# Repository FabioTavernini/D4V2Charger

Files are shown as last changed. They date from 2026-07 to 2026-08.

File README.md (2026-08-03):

# D4v2Charger

A work-in-progress proof of concept for adding built-in USB-C charging to the
[Emisar D4v2](https://intl-outdoor.com/emisar-d4v2-high-power-led-flashlight.html) flashlight, using a
pogo-pin connector in place of removing the cell to charge it externally.

The charger PCB is a disc that sits sandwiched between the flashlight body
tube and the head, in the same joint where they normally screw together. A
spring contact on the board presses against the cell's positive terminal,
while the pogo-pin connector protrudes to the side to bring in USB-C power
through the body wall.

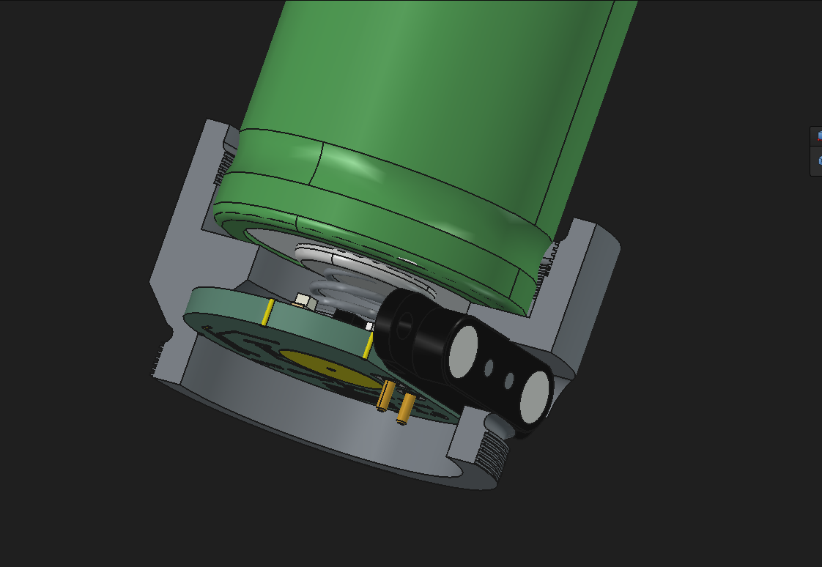
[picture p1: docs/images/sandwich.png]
SandwichBoard


*Cutaway render: cell (green) above, charger PCB sandwiched at the
body/head joint below, with the spring contact touching the cell's positive
terminal and the pogo-pin connector (black) sticking out to the side.*

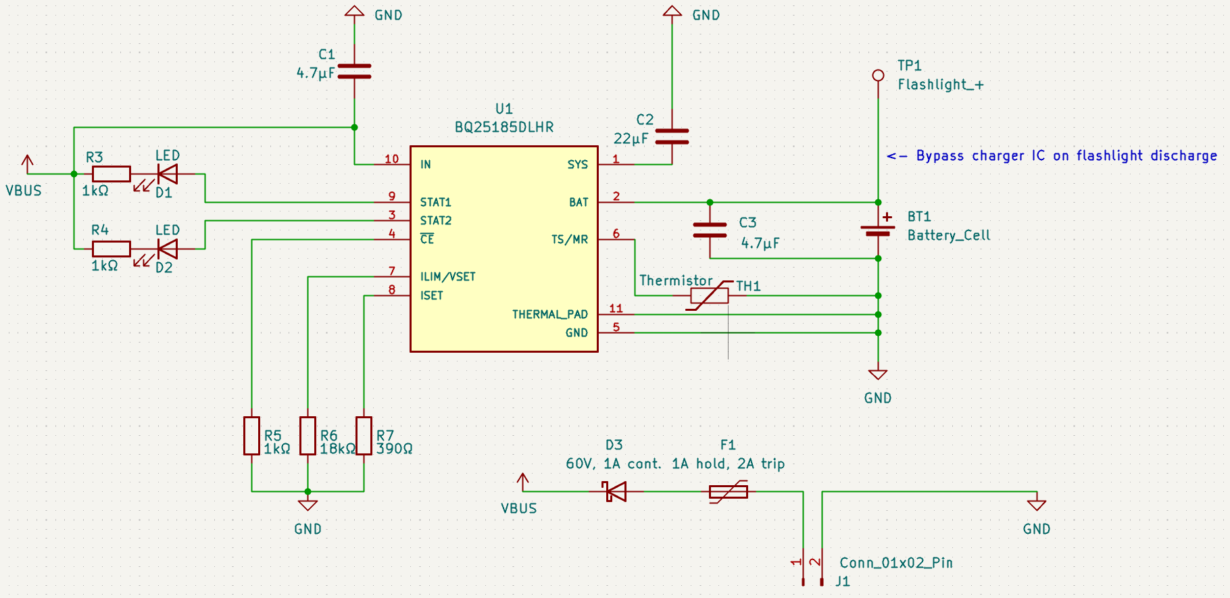
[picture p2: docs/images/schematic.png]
Schematics


*Screenshot of Schematic (May be out of date lol)*

## Status

Early prototype / proof of concept. Nothing here has been validated in a
final build yet — expect rough edges, and treat all files as subject to
change.

## How it works

- A small ring-shaped PCB is sandwiched between the flashlight body and
  head, and charges the cell via a
  [TI BQ25185](https://www.ti.com/product/BQ25185) single-cell Li-ion linear
  charger (with integrated power path).
- A spring contact on the board makes the positive connection to the cell,
  so no wiring or modification of the cell itself is needed.
- Power comes in through a pair of spring-loaded pogo pins rather than a
  connector mounted directly on the PCB, so no permanent cutout is needed
  for a USB-C receptacle on the board itself.
- A custom pogo-pin connector part and a modified flashlight body/case were
  designed to accommodate the charging contacts and let the PCB sandwich
  fit at the body/head joint.

## Repo contents

- `pcb/` — KiCad project for the charger board
  - `D4v2Charger.kicad_pro` / `.kicad_sch` / `.kicad_pcb` — schematic and PCB layout
  - `D4v2Charger.step` — 3D export of the finished board
  - `PogoPinConnector/` — FreeCAD model and STEP export of the pogo-pin connector
  - `D4v2Charger-backups/` — automatic KiCad backups (safe to ignore)
- `case/` — FreeCAD model of the modified flashlight body/case to fit the
  charging hardware

## Tools used

- [KiCad](https://www.kicad.org/) for schematic capture and PCB layout
- [FreeCAD](https://www.freecad.org/) for mechanical/case design

## Disclaimer

This is a hobbyist mod to a battery-powered lighting device. Modifying
charging circuitry and battery contacts carries fire/safety risk if done
incorrectly. Use at your own risk.

## License

Licensed under the [CERN Open Hardware Licence Version 2 - Strongly
Reciprocal](LICENSE) (CERN-OHL-S-2.0).

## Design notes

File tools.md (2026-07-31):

# Tools

Equipment needed to actually build and fit this board, beyond the parts in
[`BOM.csv`](./BOM.csv) and the design files in [`pcb/`](./pcb) and
[`case/`](./case). Software used to design the project (KiCad, FreeCAD) is
listed in the main [README](./README.md#tools-used).

## PCB assembly

The board is a 1.6mm, 2-layer design with parts on both sides, and the
smallest packages are the 0402 caps/resistors — hand-placing those without
a stencil is the fiddly part. Planned process: manual paste dotting +
hot plate reflow (no stencil ordered, board too small to justify it).

- Hot plate (cheap AliExpress hot plate + controller kit) as the reflow
  source. Heat conducts up through the board copper, so it also reflows
  the BQ25185's exposed thermal pad fine without needing hot air.
- Solder paste in a syringe with a fine (~22-25ga) blunt needle tip, for
  dotting paste onto pads by hand since there's no stencil — this is the
  part that needs the most care at 0402 size
- Fine-tip soldering iron for touch-up/rework and for the through-hole
  pogo-pin/spring contact if it isn't reflowed
- Kapton tape or similar heat-safe tape to hold the board flat/in place
  on the hot plate
- Flux pen + isopropyl alcohol for cleanup after soldering
- Fine ESD tweezers and a magnifier/loupe or microscope — needed for
  placing 0402 passives and 0603 LEDs, and for nudging the BQ25185 into
  place on its 0.4mm-pitch pads
- Multimeter, for continuity/short checks before power-up, especially
  since the board edge is copper-plated and acts as the ground/negative
  contact against the flashlight case — an accidental bridge here is a
  direct short across the cell
- USB-C power source (a basic 5V source is enough, no PD negotiation
  needed) to test charging once assembled
- Bench power supply / current-limited source recommended for first
  power-up, to catch a bad solder joint before it takes the cell with it

## Case & mechanical fit

The case mod and pogo-pin connector are custom FreeCAD parts
(`case/Case.FCStd`, `pcb/PogoPinConnector/`), fitted into the D4v2's
body/head threaded joint (`case/Thread_tests/ThreadTester.FCStd`):

- Means to cut/print the modified body threads to match the D4v2's
  joint — a tap matching the body's thread pitch if machining an
  existing aluminum body, or a 3D printer/CNC if producing a test or
  replacement part. Print/machine and check fit with the thread tester
  model before committing to the real body.
- Calipers, to confirm the sandwiched board's thickness and the pogo-pin
  standoff height fit the joint gap before final assembly
- Small pin press or arbor press, for seating the pogo pins into the
  connector housing without bending them
- Drill/reamer sized to the pogo-pin housing bore, if machining the body
  directly rather than printing a new part

## Final assembly

- No tools needed to reassemble the body/head — it's a hand-tightened
  threaded joint
- Isopropyl alcohol and lint-free wipes for a final clean before closing
  everything up (flux residue near the cell contact is worth avoiding)

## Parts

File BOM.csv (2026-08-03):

Id | Designator | Footprint | Quantity | Designation | Supplier and ref | comment | Link | price
1 | TP1 | TestPoint_Pad_D6.0mm_spring | 1 | Flashlight_+ |  | Spring, 6mm diameter 25° banking if available, for + terminal | https://de.aliexpress.com/item/1005005667884016.html
2 | U1 | Texas_DLH0010A_WSON-10-1EP_2.2x2mm_P0.4mm_EP0.9x1.5mm | 1 | BQ25185DLHR |  | digikey, pretty expensive | https://www.digikey.com/en/products/detail/texas-instruments/BQ25185DLHR/21769368 | 2.28
3 | D3 | DIO_PMEG6010CEJF | 1 | 60V, 1A cont. |  | not available, see alternatives | https://de.aliexpress.com/item/1005012406460192.html
4 | D1,D2 | LED_0603_1608Metric | 2 | LED |  | 1000pcs reel | https://de.aliexpress.com/item/1005009084941790.html | 4.25
5 | C2 | C_0402_1005Metric | 1 | 22µF |  | 50pcs | https://de.aliexpress.com/item/1005005108653334.html | 3.47
6 | C1,C3 | C_0402_1005Metric | 2 | 4.7µF |  | 6.3v 50pcs | https://de.aliexpress.com/item/1005012364450156.html | 1.31
7 | R4,R5,R3 | R_0402_1005Metric | 3 | 1kΩ |  | 100pcs | https://de.aliexpress.com/item/1005008851185252.html | 0.21
8 | R6 | R_0402_1005Metric | 1 | 18kΩ |  |  | https://de.aliexpress.com/item/1005008851185252.html | 0.21
9 | R7 | R_0402_1005Metric | 1 | 390Ω |  |  | https://de.aliexpress.com/item/1005008851185252.html | 0.21
10 | F1 | 0402L100SLKR | 1 | 1A hold, 2A trip |  | digikey, pretty expensive | https://www.digikey.com/en/products/detail/littelfuse-inc/0402L100SLKR/12807017 | 3.28
11 | J1 | PinHeader_1x02_P2.54mm_Vertical | 1 | Conn_01x02_Pin |  | 5pcs | https://de.aliexpress.com/item/1005006531774076.html | 10.39
12 | TH1 | THERM_NTCG103JF103FT1 | 1 | Thermistor |  | TDK NTCG103JF103FT1, 10kΩ NTC 0402

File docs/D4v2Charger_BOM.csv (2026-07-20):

Id | Designator | Footprint | Quantity | Designation | Supplier and ref
1 | TP1 | TestPoint_Pad_D6.0mm_spring | 1 | Flashlight_+
2 | U1 | Texas_DLH0010A_WSON-10-1EP_2.2x2mm_P0.4mm_EP0.9x1.5mm | 1 | BQ25185DLHR
3 | D3 | DIO_PMEG6010CEJF | 1 | 60V, 1A cont.
4 | D1,D2 | LED_0603_1608Metric | 2 | LED
5 | C2 | C_0402_1005Metric | 1 | 22µF
6 | C1,C3 | C_0402_1005Metric | 2 | 4.7µF
7 | R4,R5,R3 | R_0402_1005Metric | 3 | 1kΩ
8 | R6 | R_0402_1005Metric | 1 | 18kΩ
9 | R7 | R_0402_1005Metric | 1 | 390Ω
10 | F1 | 0402L100SLKR | 1 | 1A hold, 2A trip
11 | J1 | PinHeader_1x02_P2.54mm_Vertical | 1 | Conn_01x02_Pin
12 | R8 | R_0402_1005Metric | 1 | 10kΩ

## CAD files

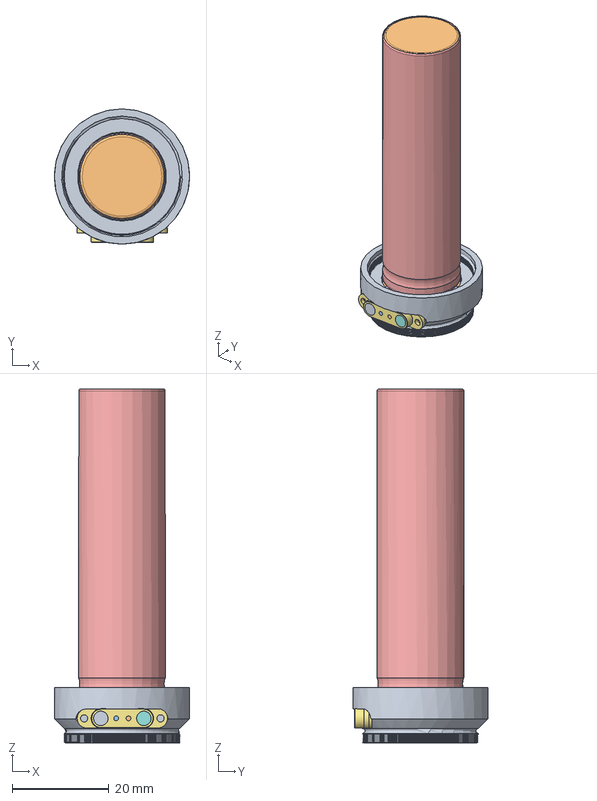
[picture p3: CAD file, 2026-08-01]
case/Case.FCStd
28.0 x 28.0 x 73.3 mm
18650 Battery
18650 Battery001
18650 Battery002
18650 Battery003
Spring_6mm-Body
Texas_DLH0010A_WSON-10-1EP_2.2x2mm_P0.4mm_EP0.9x1.5mm
Pads
Pads001
LED_0603_1608Metric
C_0402_1005Metric
C_0402_1005Metric001
LED_0603_1608Metric001
R_0402_1005Metric
R_0402_1005Metric001
R_0402_1005Metric002
R_0402_1005Metric003
Pads003
Pads004
DiodeBody
R_0402_1005Metric004
Magnets
Magnets001
Pads006
Pads007
Pins
Pins001
C_0402_1005Metric002
NTCG103JF103FT1
NTCG103JF103FT001
NTCG103JF103FT002
D4v2Charger_copper
D4v2Charger_copper001
D4v2Charger_copper002
D4v2Charger_copper003
D4v2Charger_copper004
D4v2Charger_copper005
D4v2Charger_copper006
D4v2Charger_copper007
D4v2Charger_copper008
D4v2Charger_copper009
D4v2Charger_copper010
D4v2Charger_copper011
D4v2Charger_copper012
D4v2Charger_copper013
D4v2Charger_copper014
D4v2Charger_copper015
D4v2Charger_copper016
D4v2Charger_copper017
D4v2Charger_copper018
D4v2Charger_copper019
D4v2Charger_copper020
D4v2Charger_copper021
D4v2Charger_copper022
D4v2Charger_copper023
D4v2Charger_pad
D4v2Charger_pad001
D4v2Charger_pad002
D4v2Charger_pad003
D4v2Charger_pad004
D4v2Charger_pad005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

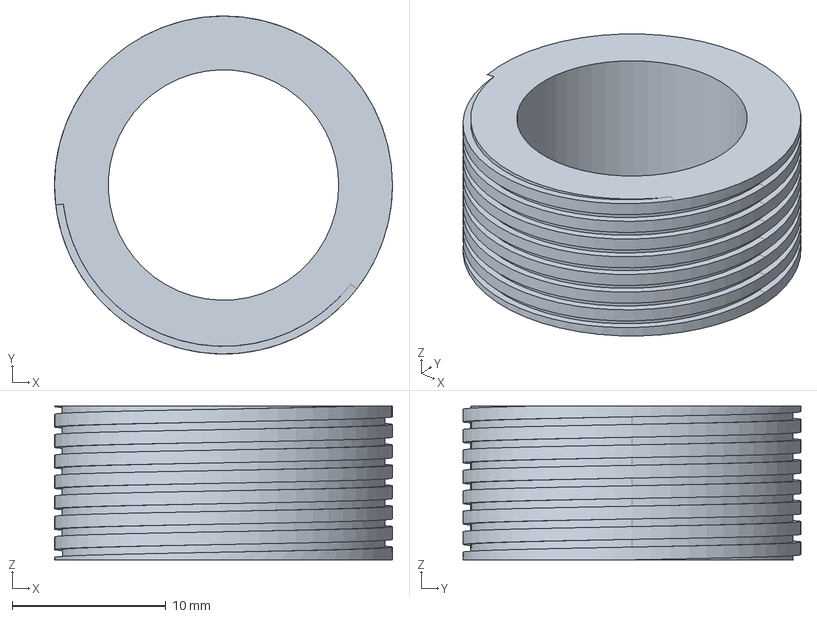
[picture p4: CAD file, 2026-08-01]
case/Thread_tests/ThreadTester.FCStd
22.0 x 22.0 x 10.0 mm

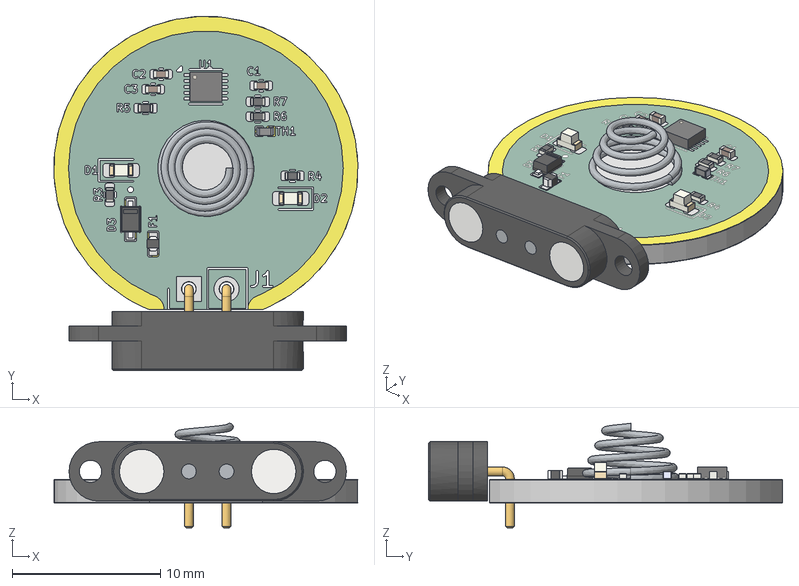
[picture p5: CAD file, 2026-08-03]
pcb/D4v2Charger.step
20.5 x 23.9 x 7.05 mm
Spring_6mm-Body
Texas_DLH0010A_WSON-10-1EP_2.2x2mm_P0.4mm_EP0.9x1.5mm
Pads x 3
LED_0603_1608Metric x 2
C_0402_1005Metric x 3
R_0402_1005Metric x 5
DiodeBody
Magnets
Pins
NTCG103JF103FT1
D4v2Charger_copper
D4v2Charger_pad
D4v2Charger_via
D4v2Charger_silkscreen
D4v2Charger_soldermask
D4v2Charger_PCB

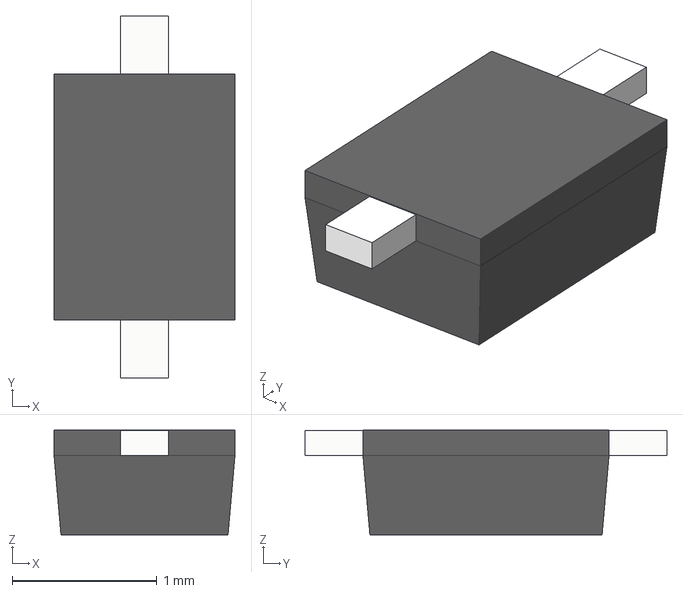
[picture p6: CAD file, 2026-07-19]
pcb/DIO_PMEG6010CEJF/DIO_PMEG6010CEJF.step
1.25 x 2.50 x 0.725 mm
Pads

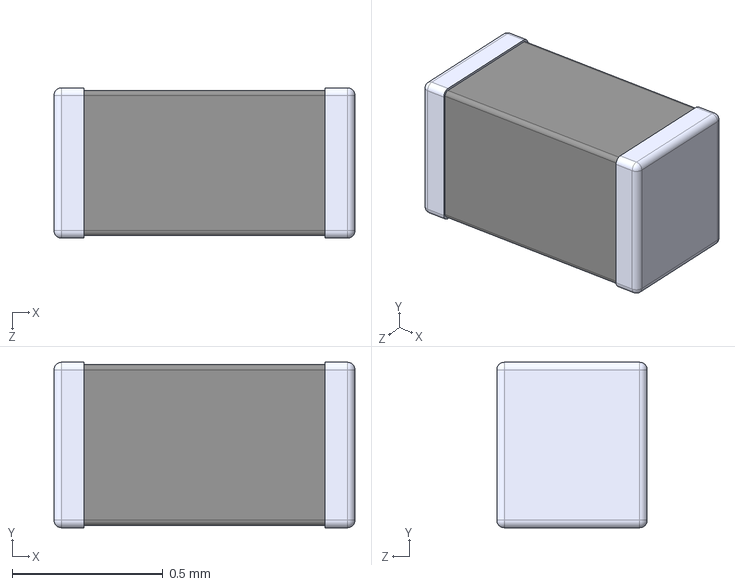
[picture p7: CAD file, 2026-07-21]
pcb/NTCG103JF103FT1/NTCG103JF103FT1.step
1.00 x 0.55 x 0.5 mm

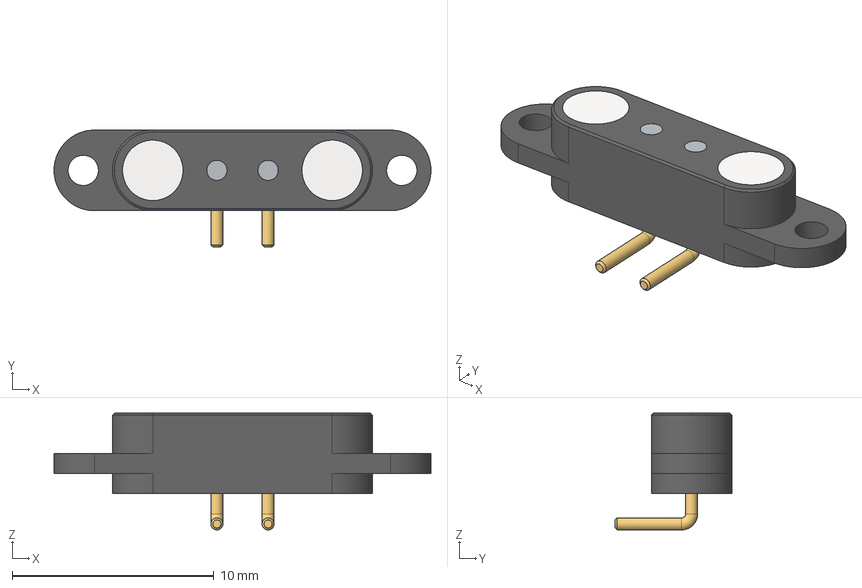
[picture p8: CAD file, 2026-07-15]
pcb/PogoPinConnector/PogoPinConnector.step
18.7 x 5.80 x 5.80 mm
Magnets
Pads
Pins

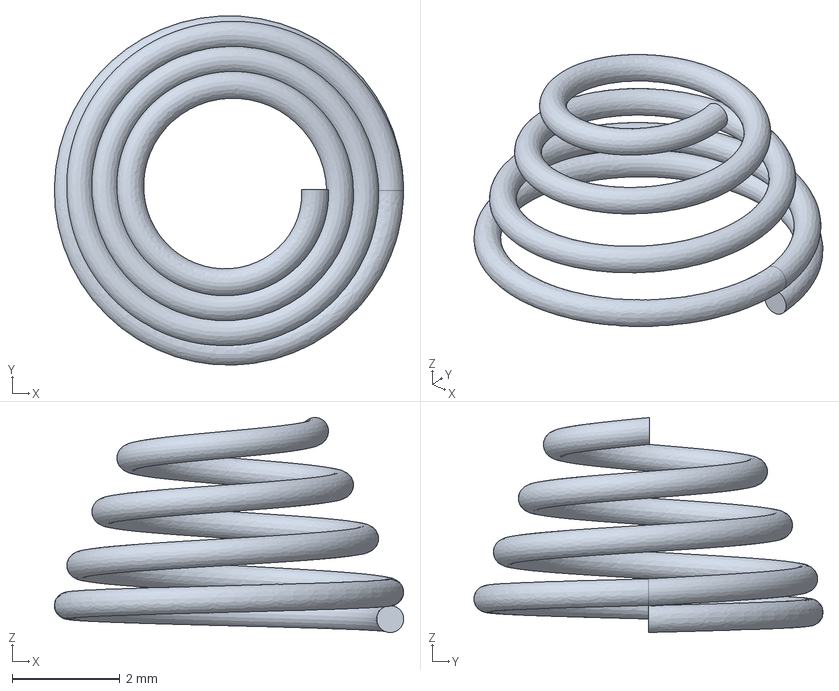
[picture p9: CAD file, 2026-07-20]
pcb/TestPad_SpringModel/Spring_6mm.FCStd
6.50 x 6.49 x 4.00 mm

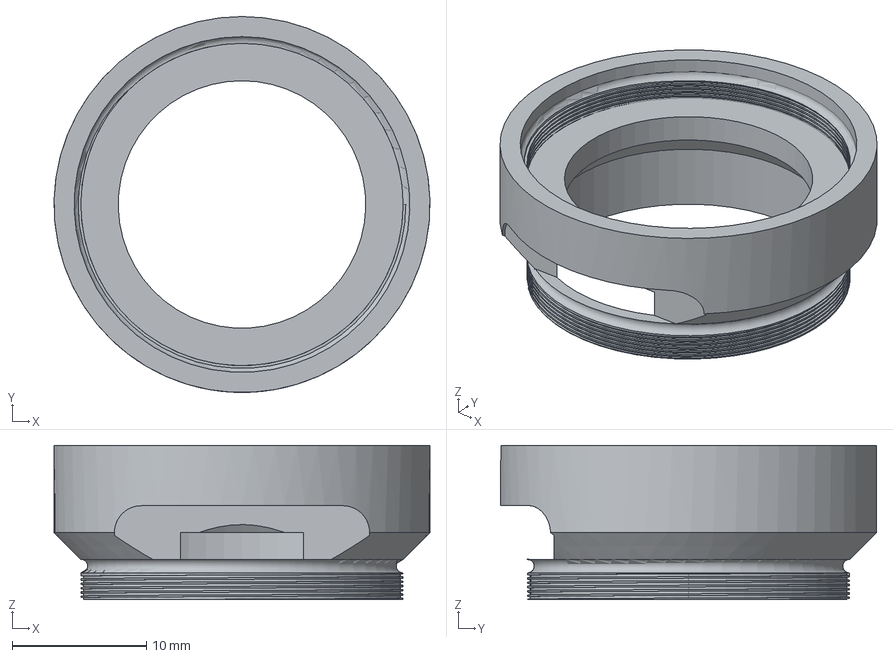
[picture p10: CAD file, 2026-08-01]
case/Case-Body.step
28.0 x 28.0 x 11.5 mm

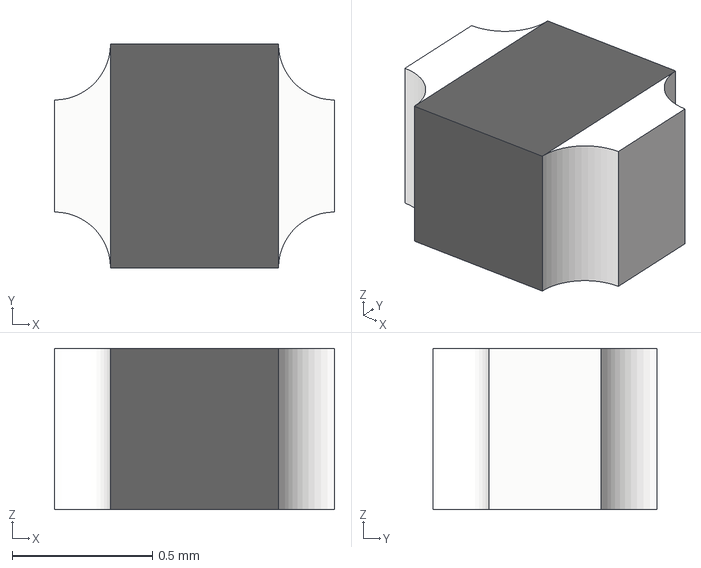
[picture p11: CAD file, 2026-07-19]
pcb/Littlefuse_0406L_0402L100SLKR_0402L100SL/0402L100SL.step
1.00 x 0.8 x 0.575 mm
Pads
DiodeBody

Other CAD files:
case/Thread_tests/ThreadTester-Male.step
pcb/TestPad_SpringModel/Spring_6mm-Body.step
pcb/DIO_PMEG6010CEJF/DIO_PMEG6010CEJF.FCStd
pcb/Littlefuse_0406L_0402L100SLKR_0402L100SL/0402L100SL.FCStd
pcb/PogoPinConnector/PogoPinConnector.FCStd

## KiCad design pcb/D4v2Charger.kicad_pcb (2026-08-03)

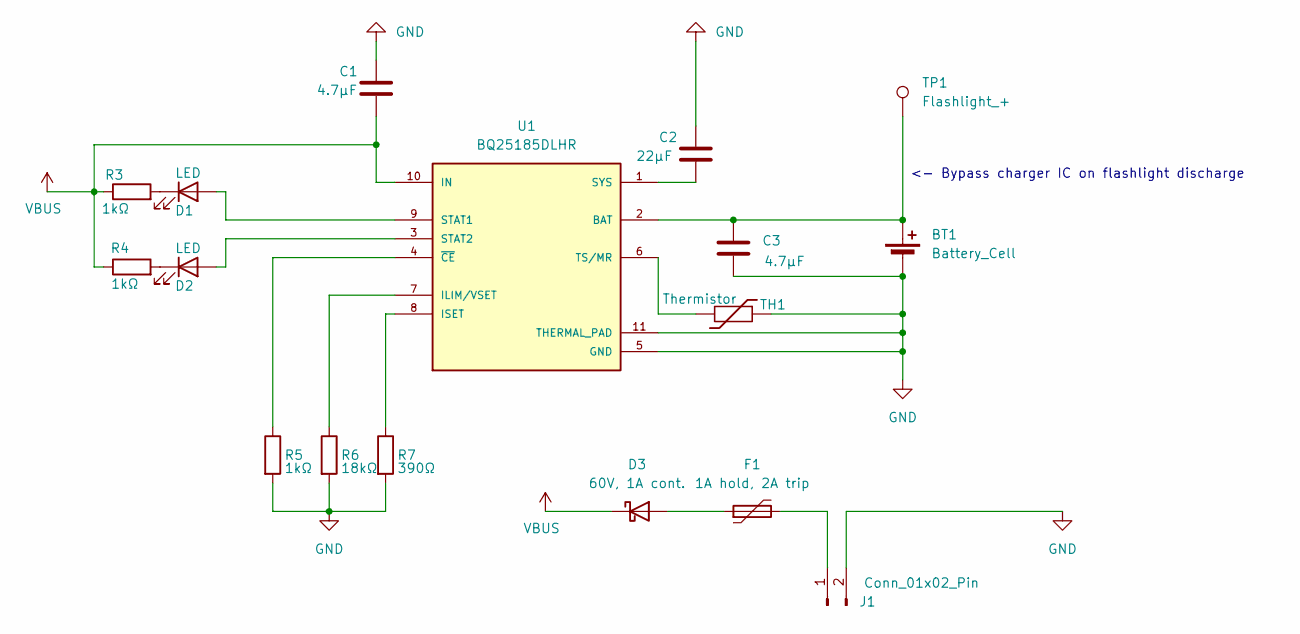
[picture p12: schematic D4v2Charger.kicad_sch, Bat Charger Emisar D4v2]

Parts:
BT1: Battery_Cell
C1, C3: 4.7µF; C_0402_1005Metric
C2: 22µF; C_0402_1005Metric
D1, D2: LED; LED_0603_1608Metric
D3: 60V, 1A cont.; DIO_PMEG6010CEJF
F1: 1A hold, 2A trip; 0402L100SLKR
J1: Conn_01x02_Pin; PinHeader_1x02_P2.54mm_Vertical
R3, R4, R5: 1kΩ; R_0402_1005Metric
R6: 18kΩ; R_0402_1005Metric
R7: 390Ω; R_0402_1005Metric
TH1: Thermistor; THERM_NTCG103JF103FT1
TP1: Flashlight_+; TestPoint_Pad_D6.0mm_spring
U1: BQ25185DLHR; Texas_DLH0010A_WSON-10-1EP_2.2x2mm_P0.4mm_EP0.9x1.5mm; PARTREV OCTOBER 2023

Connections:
GND: BT1.2 (-), C1.1, C2.1, C3.2, J1.2, R5.2, R6.2, R7.2, TH1.1, U1.5 (GND), U1.11 (THERMAL_PAD)
unnamed: BT1.1 (+), C3.1, TP1.1, U1.2 (BAT)
unnamed: D1.2 (A), U1.9 (STAT1)
unnamed: D1.1 (K), R3.2
unnamed: D2.2 (A), U1.3 (STAT2)
unnamed: D2.1 (K), R4.2
unnamed: D3.2 (A), F1.1
unnamed: F1.2, J1.1
unnamed: R6.1, U1.7 (ILIM/VSET)
unnamed: R7.1, U1.8 (ISET)
unnamed: C2.2, U1.1 (SYS)
unnamed: TH1.2, U1.6 (TS/MR)
unnamed: R5.1, U1.4 (~CE)
VBUS: C1.2, D3.1 (K), R3.1, R4.1, U1.10 (IN)

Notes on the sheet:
<- Bypass charger IC on flashlight discharge

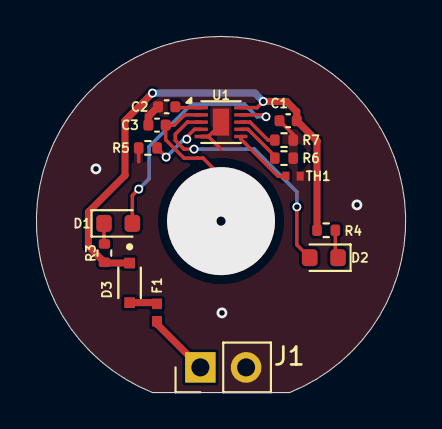
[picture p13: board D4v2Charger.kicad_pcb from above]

Board: 2 copper layers, 20.5 x 19.8 mm, 16 parts (0 on the bottom side), 14 nets.

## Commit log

2026-07-15 add rest of files
    [Case.FCStd, D4v2Charger.kicad_pcb, D4v2Charger.kicad_sch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]
2026-07-15 updates & license addition
    [Case.FCStd, D4v2Charger.kicad_pcb, D4v2Charger.kicad_sch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]
2026-07-15 updated pcb clearance for magnetic charger
    [D4v2Charger.kicad_pcb, D4v2Charger.kicad_sch]
2026-07-15 re-import pcb
    [Case.FCStd, D4v2Charger.step]
2026-07-15 import step case as linkgroup
    [Case.FCStd, D4v2Charger.kicad_pcb]
2026-07-16 SYS pin fix
2026-07-19 create diode 3dModel
    [D4v2Charger.kicad_pcb, D4v2Charger.kicad_sch, DIO_PMEG6010CEJF.FCStd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]
2026-07-19 create fuse 3dmodel
    [0402L100SL.FCStd, 0402L100SL.step, D4v2Charger.kicad_pcb]
2026-07-20 3dFootprint updates
    [Case.FCStd, D4v2Charger.kicad_pcb, D4v2Charger.kicad_sch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]
2026-07-20 updated step file & re-import
    [Case.FCStd, D4v2Charger.kicad_pcb, D4v2Charger.step]
2026-07-20 update pcb with spring contact for battery +
    [Case.FCStd, D4v2Charger.kicad_pcb, D4v2Charger.kicad_sch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]
2026-07-20 add screenshot and 18650 into model
    [Case.FCStd]
2026-07-20 add BOM
    [D4v2Charger_BOM.csv]
2026-07-20 update BOM
    [D4v2Charger.csv]
2026-07-21 add ntcg thremistor & drc resolve
    [D4v2Charger.kicad_pcb, D4v2Charger.kicad_sch, NTCG103JF103FT1.step]
2026-07-21 gerber export & clearance finalization
    [D4v2Charger-B_Cu.gbr, D4v2Charger-B_Mask.gbr, D4v2Charger-B_Paste.gbr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]
2026-07-21 re-import pad contact for 3dmodel
    [D4v2Charger.kicad_pcb]
2026-07-21 add thread testing 3dmodel
    [ThreadTester.FCStd]
2026-07-29 add board edge copper
    [D4v2Charger.kicad_pcb]
2026-07-31 add tools.md
    [BOM.csv]
2026-07-31 rename + mention pogo legs
2026-07-31 update gerber files
    [D4v2Charger-B_Cu.gbr, D4v2Charger-B_Mask.gbr, D4v2Charger-B_Paste.gbr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]
2026-07-31 pcb update (radius)
    [Case.FCStd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]
2026-07-31 re-export gerber files
    [D4v2Charger-B_Cu.gbr, D4v2Charger-B_Mask.gbr, D4v2Charger-B_Paste.gbr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]
2026-08-01 re-import pcb stepfile
    [Case.FCStd, D4v2Charger.kicad_pcb, D4v2Charger.step]
2026-08-01 thread tester
    [Case-Body.step, Case.FCStd, ThreadTester-Male.step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]
2026-08-01 add gnd stitch vias
    [D4v2Charger.kicad_pcb]
2026-08-03 update BOM and schematic
    [D4v2Charger.csv, D4v2Charger.kicad_sch]
2026-08-03 add screenshot
    [D4v2Charger.kicad_sch]
2026-08-03 update edge cuts
    [D4v2Charger.kicad_pcb, D4v2Charger.step]
2026-08-03 add testpad
    [D4v2Charger.kicad_pcb]

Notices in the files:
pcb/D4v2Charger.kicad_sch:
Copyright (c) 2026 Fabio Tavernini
